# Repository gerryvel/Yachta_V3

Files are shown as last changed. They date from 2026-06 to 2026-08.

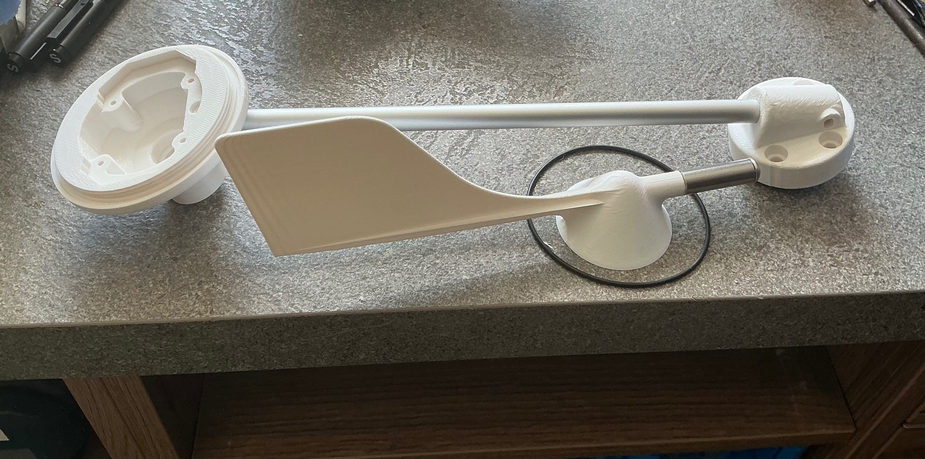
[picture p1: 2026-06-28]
Bilder/IMG_4713.jpg

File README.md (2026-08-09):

# Yachta V3





## Description

This repository describes the installation of the "Yachta V3" wind sensor.

## Based on the work of
 
The Yachta V3 is the Windsensor "Yachta" [@norbert-walter](https://github.com/norbert-walter/Windsensor_Yachta) with the modification from a french user in the www.segeln-forum.de .
You can use the following threads (in German):
- https://www.segeln-forum.de/thread/67401-windsensor-diy/
- https://www.segeln-forum.de/thread/83726-windsensor-yachta-probleml%C3%B6sungen/

This project is part of [OpenBoatProject](https://open-boat-projects.org/)

## Sensor Modul

The PCB is the same as Yachta V2. A complete system with NMEA2000 connection can be created with the NMEA2000_TPW sensor.

## Hardware




## Partlist:

### 1 Print parts
 - 1.1  Windfahne
 - 1.2  Gewindering Lager Windfahne
 - 1.3  Gehäuse-Oberteil
 - 1.4  Gehäuse-Unterteil
 - 1.5  Windlöffel 3x
 - 1.6  Löffelhalter
 - 1.7  Abstandsstück (zwischen Löffellager)
 - 1.8  Magnethalter
 - 1.9  Halterbasis
 - 1.10 Unterlegscheibe 0,5mm (ggf. mehrfach als zusätzlichen Abstandshalter)
### 2 Bearings
 - 2.1  Lager 2x 625 (5x16x5 mm SS2 HC 624 offen trocken Hybrid Keramik/Edelstahl) [link](https://www.kugellager-express.de/keramik-hybrid-miniatur-kugellager-ss-hc-625-tn-offen-trocken-5x16x5-mm)
 - 2.2  Lager 1x 695 (5x13x4 mm SS2 HC 695 offen trocken Hybrid Keramik/Edelstahl) [link](https://www.kugellager-express.de/hybrid-keramik-edelstahl-miniatur-kugellager-ss2-hc-695-offen-tn-cn-trocken-5x13x4-mm)
### 3 Norm parts
 - 3.1  Inbus-Schraube VA 1x M3x10 Zylinderkopf (Befestigung Aluminiumrohr)
 - 3.2  Inbus-Schraube VA 1x M5x20 Zylinderkopf (Befestigung Lager Windfahne)
 - 3.3  Inbus-Schraube VA 1x M5x40 Zylinderkopf (Befestigung Löffellager)
 - 3.4  Inbus-Schraube VA 1x M6x40 Linsenkopf (Gegengewicht Windfahne)
 - 3.5  Mutter VA 1x M5 (Löffellager)
 - 3.6  Unterlegscheibe VA 2x M5
 - 3.7  Inbus-Schraube VA 4x M3x7 Linsenkopf (Befestigung Leiterplatte)
### Special parts
 - 4  Aluminiumrohr 10x1mm, 200mm
 - 5  Distanzmutter rund A2 M 6x30 (Gewicht für Windspitze)
 - 6  LiYY 2x0,5 mm² oder YSLY 2x0,5 mm² ca. 300mm
 - 7  O-Ring 70x1,8 
 - 8  Leiterplatte
 - 9  Magnete: 4× Zylindermagnete Ø1,5 mm × 5 mm und 1× Würfelmagnet 5×5×5 mm
   
## Versions

- 1.2 Change 1.4  Gehäuse-Unterteil by Scorgan
- 1.1 Change parts 3.4 and 5
- 1.0 initial Version

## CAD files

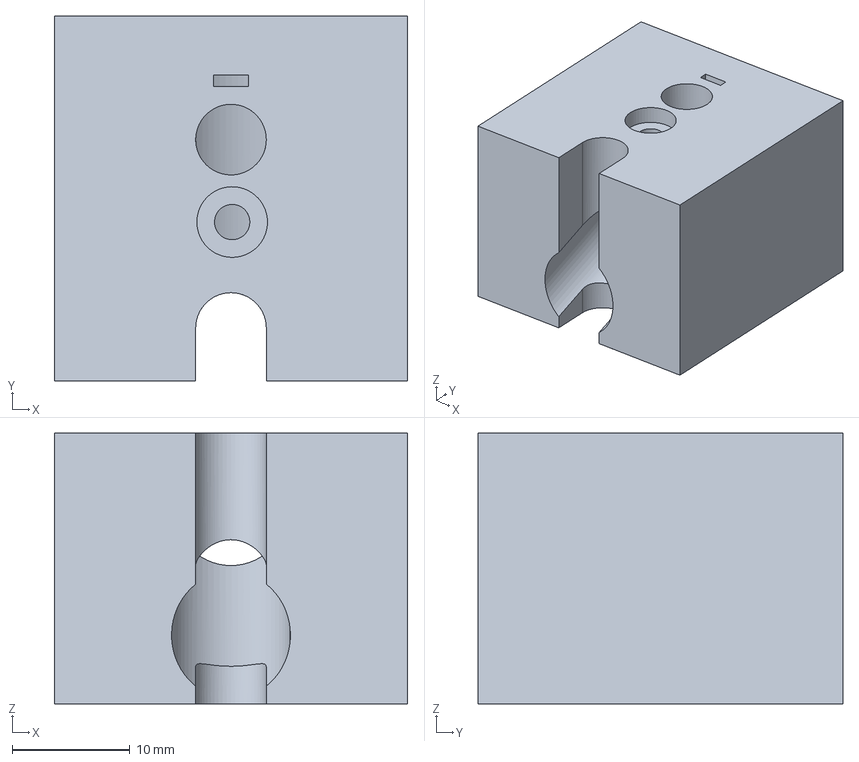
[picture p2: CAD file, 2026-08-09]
FreeCAD/V1-5mm.FCStd
30.0 x 31.0 x 23.0 mm

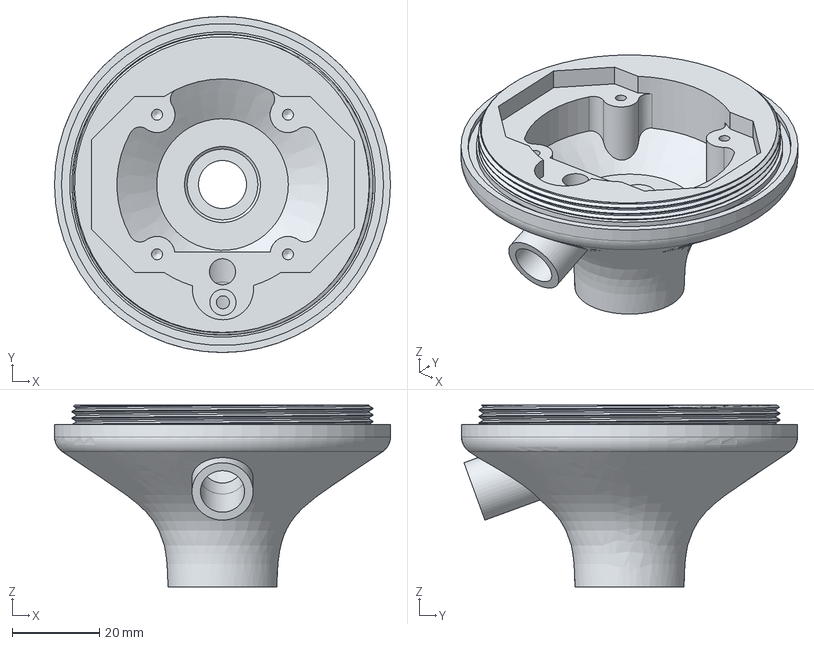
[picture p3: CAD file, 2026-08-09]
V3_Step/mod_extended_rod_support/V1-5mm - Lower body.step
77.0 x 77.0 x 41.6 mm

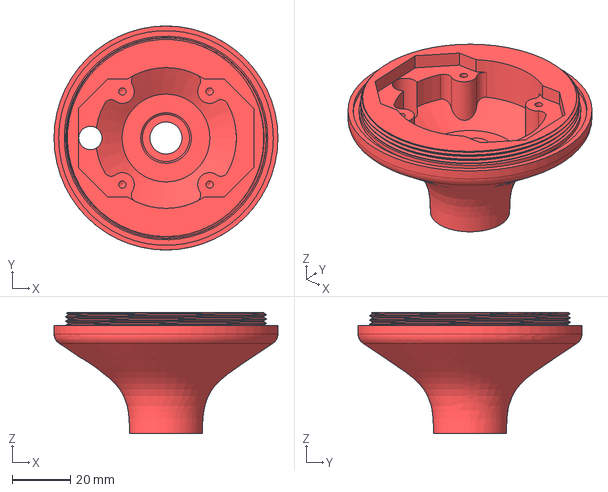
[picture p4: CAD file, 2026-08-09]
V3_Step/mod_vertical_rod/V1-5mm - Lower body.step
77.0 x 77.0 x 41.6 mm

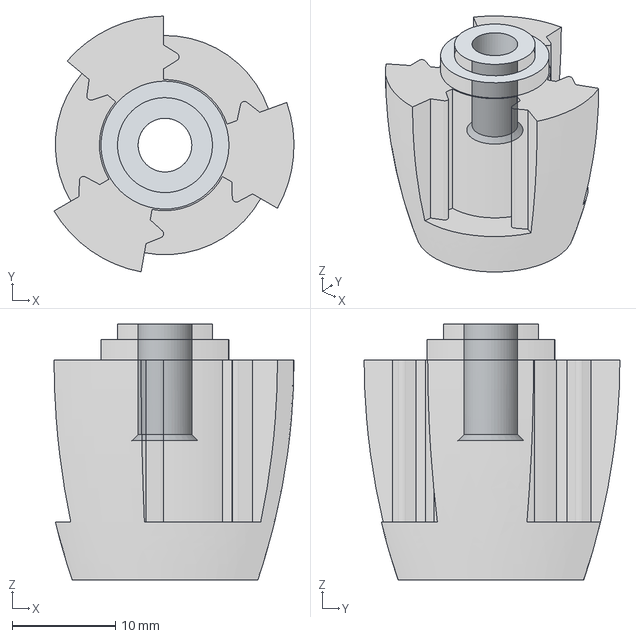
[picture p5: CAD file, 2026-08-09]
V3_Step/V1-5mm - Cup holder.step
23.2 x 24.8 x 24.8 mm

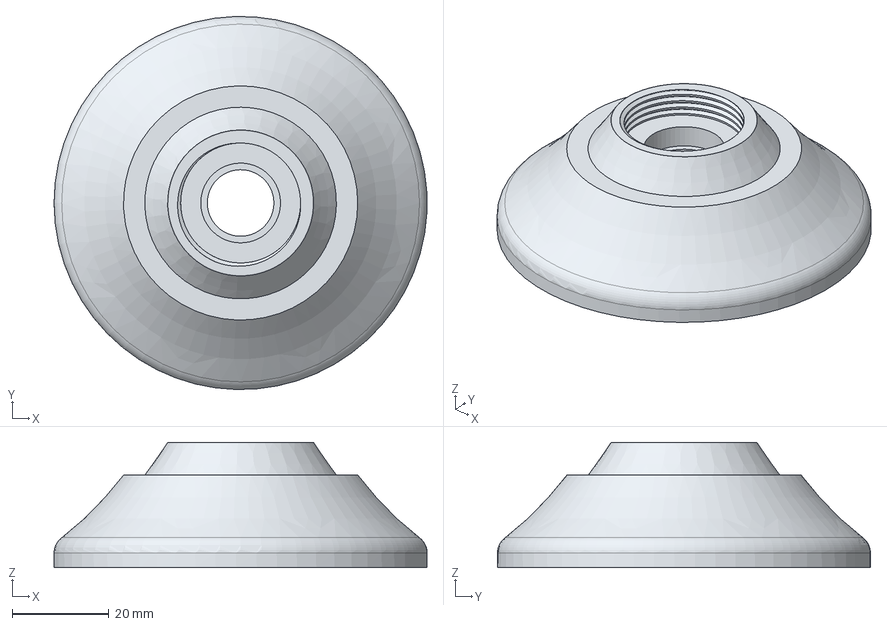
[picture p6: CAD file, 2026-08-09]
V3_Step/V1-5mm - Upper body.step
77.0 x 77.0 x 25.8 mm

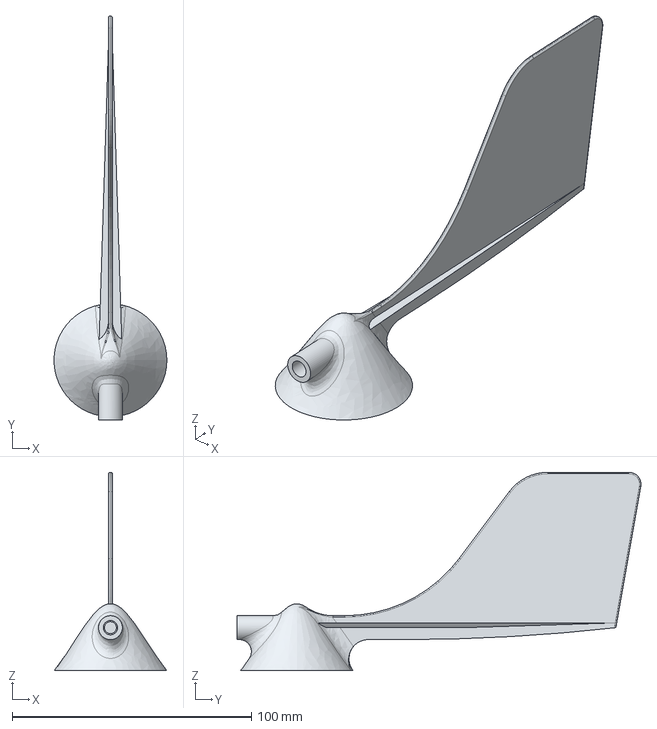
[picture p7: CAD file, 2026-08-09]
V3_Step/V1-5mm - Vane.step
47.2 x 169.0 x 83.0 mm

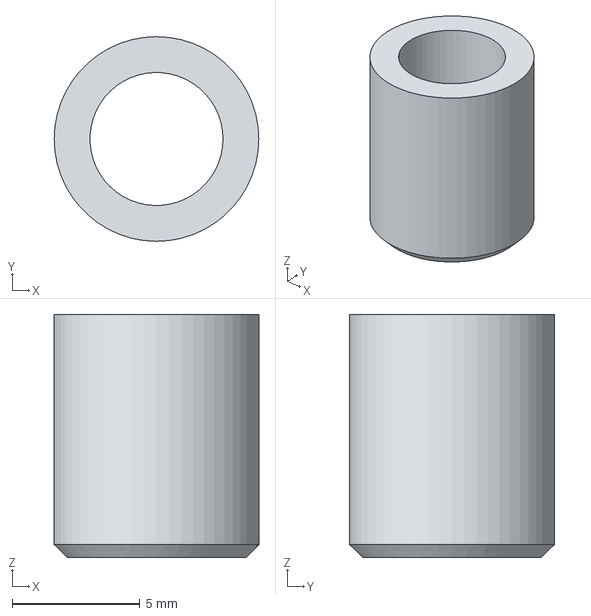
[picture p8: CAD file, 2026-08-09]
V3_Step/V1-5mm - Spacer_BB.step
8.00 x 8.00 x 9.50 mm

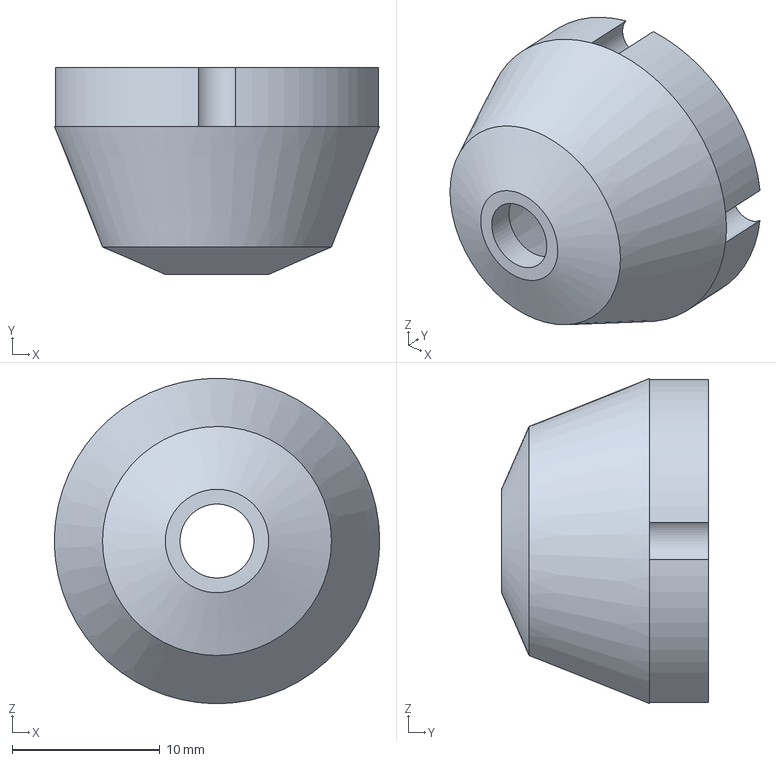
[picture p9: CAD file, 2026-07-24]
V3_Step/magnet_holder_2fase.step
22.0 x 14.0 x 22.0 mm

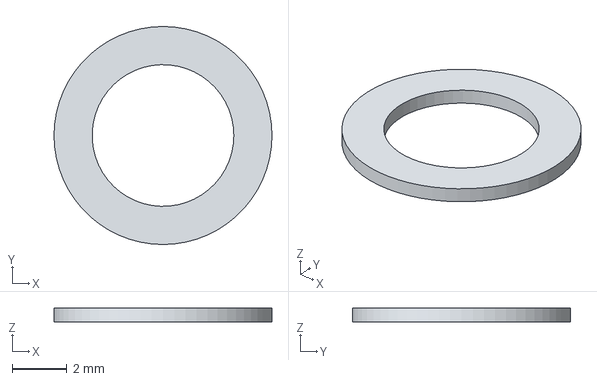
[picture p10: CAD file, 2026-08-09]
V3_Step/V1-5mm - Washer 0.5mm.step
8.00 x 8.00 x 0.5 mm

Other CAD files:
V3_Step/mod_drilling_jig/V1-5mm - Drilling jig.step
V3_Step/V1-5mm - Lower body.step

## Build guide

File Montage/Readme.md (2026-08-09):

# Werkzeuge

- Satz Schraubendreher
- Gewindefeile
- Lötbesteck
- Satz Inbusschlüssel
- Gewindeschneider M3, M5, M6
- Bohrersatz 1-10mm 0,5er Abstufung
- Feile, Schleifpapier

# Vorbereitungen

Aus der Stückliste sind alle Teile aus Pos. 1 gedruckt und die Außenteile lackiert. 
An dem Gehäuseober- und Unterteil [1.3, 1.4] muss mit der Gewindefeile (Steigung 1,5) das Gewinde ausgeräumt bzw. gesäubert werden, bis sich die beiden Teile gut zusammen- und auch wieder auseinander schrauben lassen. Vorm Lackieren zusammenschrauben, um das Gewinde sauber zu halten.

In die Windfahne [1.1] wird innen zur Befestigung der Fahne am Lager [2.1] im vorhandenem Loch M5 geschnitten. 
Ebenso das Gewinde zum Einsetzen des Gewichtsausgleiches (Schraube [3.4] mit Rohr [5]) mit M6 schneiden.
Die 4 Gewinde zur Befestigung der Leiterplatte mit M3 nachschneiden.
Die Gegengewichtsschraube [3.4] mit der VA-Distanzmutter M6x30mm [5] komplettieren. Vorher einseitig die Distanzmutter [5] innen ansenken, damit diese bündigt an den Kopf der M6 Linsenkopfschraube [3.4] passt.

# Montage
## Unterteil mit Windrad
Jetzt kann man die Windlöffel [1.5] mit dem Löffelhalter [1.6] komplettieren. In den Magnethalter [1.8] die 4 Magnete einkleben. Die Lager 1x 624 [2.2] und 1x 625 [2.1] in das Gehäuse-Unterteil einlegen, dazwischen das Abstandstück [1.7] positionieren. Die Schraube [3.3] in den Löffelhalter einführen und durch die Lager und das Abstandsstück durchfädeln, darauf die gedruckte Unterlegscheibe 0,5mm und den vormontieren Magnethalter aufsetzen und mit der Mutter M5 [3.5] verschrauben. Eventuell mit einer Unterlegscheibe [3.6] richtige Abstände einstellen, damit das Windrad frei läuft.
Auf beiden Seiten des Aluminiumrohres 10x1x200mm ist folgendes vorzubereiten:
Aluminiumstange [4] einbauen, Loch im Unterteil bzw. Fuß für M3 Schraube [3.1] anzeichnen. Alurohr wieder ausbauen, 2,5mm bohren, Gewinde M3 schneiden. 
Danach das Rohr einbauen und mit Schrauben M3 [3.1] beidseitig sichern. Kabel [6] einfädeln, Mantel absetzen und Adern abisolieren.
Leiterplatte einlegen und prüfen, ob der Abstand zu den Magneten des Magnethalters passt, eventuell anpassen. 
Die M5 Mutter mit Schraubensicherungslack sichern.

## Oberteil mit Windfahne

Im Gehäuse-Oberteil [1.3] das Lager 625 [2.1] einlegen und mit dem Gewindering [1.2] festschrauben. Mit der Schraube M5x20 [3.3] die Windfahne befestigen. Jetzt die Gegengewichtsschraube mit der Distanzmutter rund A2 M 6x30 [5] (genaue Länge durch ausbalancieren bestimmen) komplettieren, eindrehen und ausbalancieren. Eventuell mit einer Unterlegscheibe M5 den Abstand der Fahne zum Gehäuse-Oberteil einstellen. Schraube mit Lack sichern. Den Magneten 5x5x5 an den Schraubenkopf festkleben.

# Komplettieren

Kabeladern an der Leiterplatte durchfädeln, Freilauf des Magnethalters beachten. Adern anlöten. Leiterplatte mit 4x M3x7 Schrauben befestigen. O-Ring [7] einlegen und beide Schalen zusammenschrauben. Windfahne und Windrad bewegen und prüfen, ob die Magneten frei laufen und nicht an der Leiterplatte anschlagen. Halterbasis an der anderen Seite des Aluminiumrohrs anbauen, mit einer Schraube M3x10 sichern und Kabel durchfädeln.

# Inbetriebnahme 

Die weitere Inbetriebnahme nach dem Handbuch des Yachta V2 vornehmen. Siehe https://github.com/norbert-walter/Windsensor_Yachta.
Zur Einbinung in den NMEA2000 Bus kann man den [TPW_Sensor](https://github.com/gerryvel/NMEA2000_TPW) benutzen.

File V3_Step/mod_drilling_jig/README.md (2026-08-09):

Bohrschablone/Hilfe für das anpassen Halte-Rohrs.

Rohr von hinten/unten einschieben bis es eben am länglichen Schlitz sichtbar wird, dann die Löcher mit 2,5mm und 6mm Bohren.

Anschliessend das Rohr andersherum einschieben bis die 6mm Bohrung mit dem Ausschnitt am anderen Ende fluchtet. Das Loch nun nur oben zu eine Ausschnitt erweitern dabei den Aussschnitt im Block als Führung verwenden. Dann das Rohr mit dem Ende des Blocks bündig feilen.
Zuletzt noch in die 2,5mm Bohrung ein M3 Gewinde schneiden.

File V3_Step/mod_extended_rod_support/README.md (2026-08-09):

Diese Variante erweitert das Unterteil durch eine verlänerte Führung des Haltestabs. Dies wird beim FDM-Druck Supports benötigen.

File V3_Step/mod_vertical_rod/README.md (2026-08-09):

Diese Variante ersetzt das Unterteil durch eines mit einer Aufname für einen vertikalen Stab.
Dies ist die Original-Variante des Designers, erfordert aber ein gebogenes Rohr(?) um eine Kollision mit dem Schaufelrad zu vermeiden.

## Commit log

2025-12-15 Enhance assembly instructions with part references
    Added references to specific parts in the assembly instructions for clarity.
2025-12-15 Revise assembly instructions for wind turbine components
    Updated instructions for assembling the wind turbine, including changes to the aluminum rod installation and securing the M5 nut with thread locker.
2025-12-15 Revise Montage instructions for wind turbine assembly
    Updated assembly instructions for the wind turbine components, including details on magnet placement and aluminum rod installation.
2025-12-16 Update screw descriptions in README.md
2025-12-16 Revise counterweight screw details and assembly steps
    Updated the instructions for the counterweight screw and clarified assembly steps for the wind turbine.
2026-01-18 Add new screw specification to README
2026-01-18 Update assembly instructions in Readme.md
    Added instructions for securing the circuit board with screws.
2026-01-31 Fix wire size in parts list in README.md
2026-02-14 Update assembly instructions for wind vane and counterweight
2026-02-15 Update README.md
    Angaben zu den Magneten etwas genauer gemacht:
    - * 9 Magnete (4x 1,5x5 und 1x 5x5x5)
    + * 9 Magnete: 4× Zylindermagnete Ø1,5 mm × 5 mm und 1× Würfelmagnet 5×5×5 mm
2026-02-15 Update bearing specifications in README
2026-02-26 Add links to bearing specifications in README
2026-04-05 Revise counterweight screw assembly instructions
    Updated the instructions for assembling the counterweight screw with the new M6x30mm spacer nut and provided additional details for proper fitting.
2026-04-05 Clarify references in Readme for assembly instructions
2026-07-19 Fix Upper Body - scaled threads by 101% for better with FDM printing
    [V1-5mm - Upper body.step, V1-5mm.FCStd]
2026-07-19 Fix Vane - diameter of bore hole for the shaft was too small, caused problems with internal breaking when dripping/tapping
    [V1-5mm - Vane.step, V1-5mm.FCStd]
2026-07-19 Added champher to BB spacer to avoid rubbing on smaller bearing and extend by 0.5mm
    [V1-5mm - Spacer_BB.step, V1-5mm.FCStd]
2026-07-19 Added 0.5mm washer, This goes below the magnet holder to avoid rubbing on the bearing
    [V1-5mm - Washer 0.5mm.step, V1-5mm.FCStd]
2026-07-19 Extend Cup holder by 0.5mm to avoid rubbing
    [V1-5mm - Cup holder.step, V1-5mm.FCStd]
2026-07-21 Moved the old vertical rod variant of the lower body to a mod folder, to make it clear this isn't the currently recommended variant
    [V1-5mm - Lower body.step]
2026-07-21 Renamed the actual recommended lower body part to reflect that
    [V1-5mm - Lower body.step]
2026-07-21 Kabeldurchführung für Lower Body inklusive Variante mit verlängerter Rohrführung für mehr Stabilität
    [V1-5mm - Lower body.step, V1-5mm.FCStd]
2026-07-21 Switched bore holes for set screw and cable to allow for better cable management and easier installation. Added optional drilling jig.
    [V1-5mm - Drilling jig.step, V1-5mm - Lower body.step, V1-5mm.FCStd]
2026-07-24 Magnetholder change
    [magnet_holder_2fase.step]
